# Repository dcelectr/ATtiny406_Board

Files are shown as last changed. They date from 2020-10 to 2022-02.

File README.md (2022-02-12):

# ATtiny406_Board
PCB Design Files for ATtiny406 Board

This board design is a variant of a board design that is found in the blog link below.

https://www.omzlo.com/articles/baremetal-programming-on-the-tinyavr-0-micro-controllers

The board features fairly easy to hand solder components, such as a SOIC20 IC and 0805 resistors, capacitors and LEDs, and it is breadboard friendly (100 mil spacing pin headers) with an orderly pin arrangement (PA0->PA7, PB0->PB5, and PC0->PC3). 

The programming connector is a standard FTDI USB-UART adapter pin-out. Since most FTDI USB-UART cables have different voltage for the Vcc and Vttl (such as the TTL-232R-3V3), a solder jumper (JP1) is open by default. The board can be powered from the breadboard pin headers or the FTDI programming header if the the jumper JP1 is closed. Using an FTDI TTL-232RG-VIP USB-UART requires the jumper JP1 to be closed so that the TTL-232RG-VIP adapter TTL voltage (Vttl) would be the same as the Vcc.

The Bill of Materials is also included (see file ATtiny406BOM.csv).

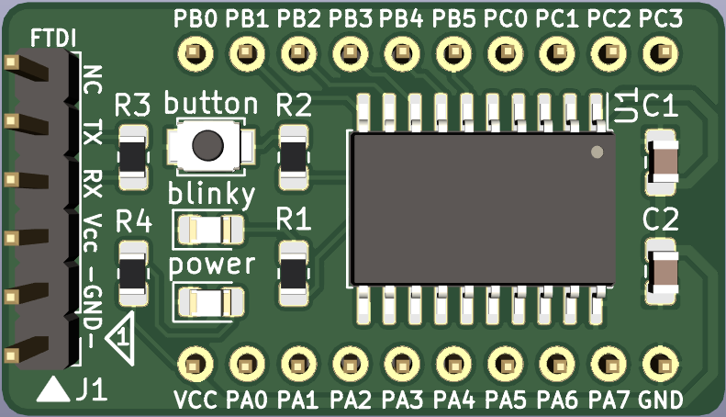
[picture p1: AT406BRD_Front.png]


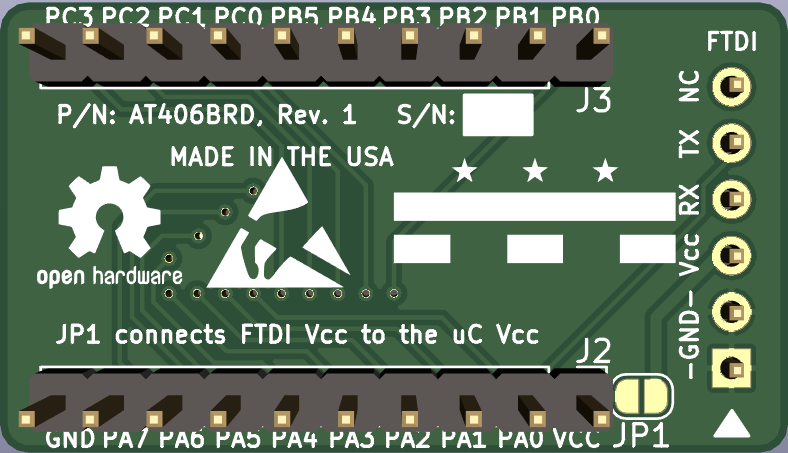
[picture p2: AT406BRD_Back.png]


Resistance of 4k7 Ohms works reliably for programming the Attiny406 over the range of Vcc, from 5V to 3V3.

Programming was tested on Linux with updiprog https://github.com/DCelectronics/updiprog (which is written in C) instead of using pyupdi.

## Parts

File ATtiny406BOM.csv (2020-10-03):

Reference | Quantity | Value | Footprint | Datasheet | P/N
C1 | 1 | 0.1uF | Capacitor_SMD:C_0805_2012Metric_Pad1.18x1.45mm_HandSolder | ~ | CC0805KRX7R7BB104
C2 | 1 | 2.2uF | Capacitor_SMD:C_0805_2012Metric_Pad1.18x1.45mm_HandSolder | ~ | CL21B225KOFNNNE
D1 | 1 | YEL | LED_SMD:LED_0805_2012Metric_Pad1.15x1.40mm_HandSolder | ~ | 150080YS75000
D2 | 1 | GRE | LED_SMD:LED_0805_2012Metric_Pad1.15x1.40mm_HandSolder | ~ | 150080VS75000
J1 | 1 | Conn_01x06_Male | Connector_PinHeader_2.54mm:PinHeader_1x06_P2.54mm_Vertical | ~ | PH1-06-UA
J2 J3 | 2 | Conn_01x10_Male | Connector_PinHeader_2.54mm:PinHeader_1x10_P2.54mm_Vertical | ~ | PH1-10-UA
JP1 | 1 | Jumper_2_Open | Jumper:SolderJumper-2_P1.3mm_Open_RoundedPad1.0x1.5mm | ~ | N/A
R1 R2 R4 | 3 | 1K | Resistor_SMD:R_0805_2012Metric_Pad1.20x1.40mm_HandSolder | ~ | ERJ-6GEYJ102V
R3 | 1 | 4K7 | Resistor_SMD:R_0805_2012Metric_Pad1.20x1.40mm_HandSolder | ~ | ERJ-6GEYJ472V
SW1 | 1 | SW_Push | Button_Switch_SMD:SW_SPST_B3U-1000P | ~ | B3U-1000P
U1 | 1 | ATtiny406-S | Package_SO:SOIC-20W_7.5x12.8mm_P1.27mm | http://ww1.microchip.com/downloads/en/DeviceDoc/Microchip%208bit%20mcu%20AVR%20ATtiny406%20data%20sheet%2040001976A.pdf | ATTINY406-SFR

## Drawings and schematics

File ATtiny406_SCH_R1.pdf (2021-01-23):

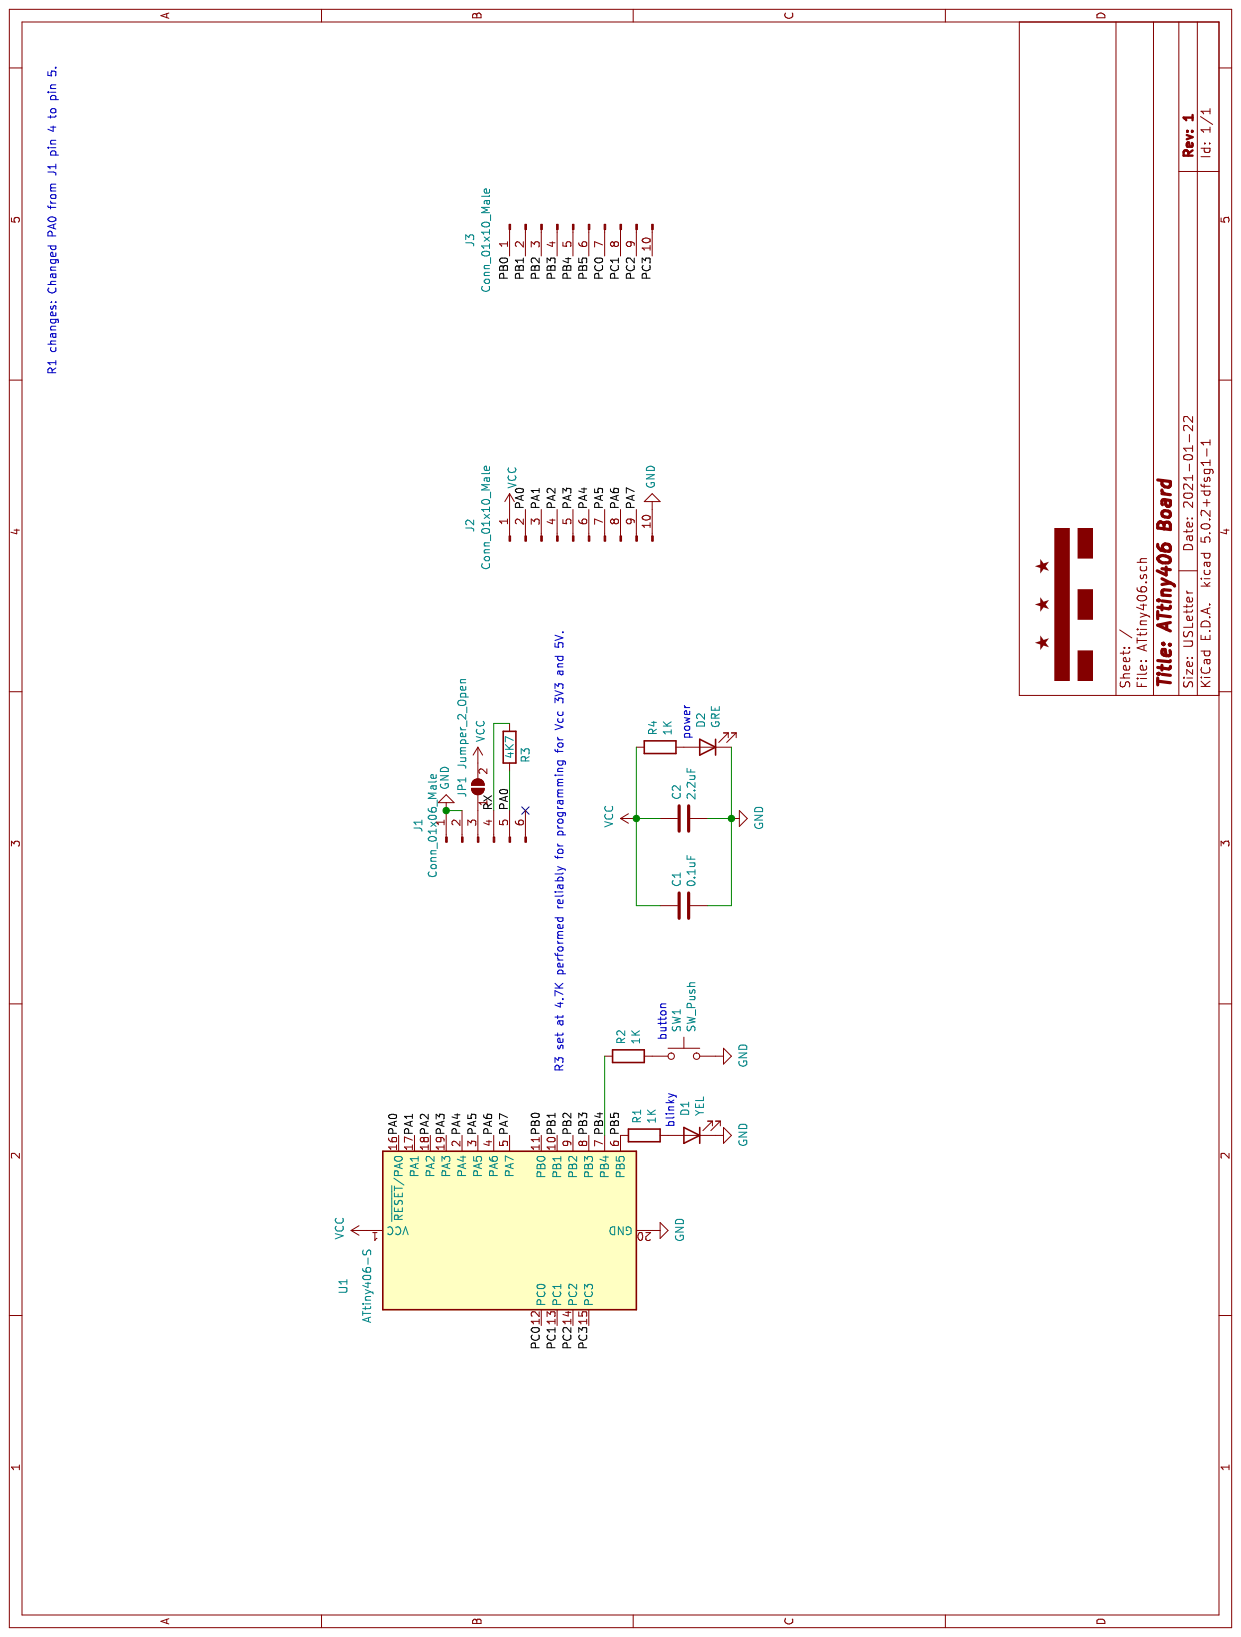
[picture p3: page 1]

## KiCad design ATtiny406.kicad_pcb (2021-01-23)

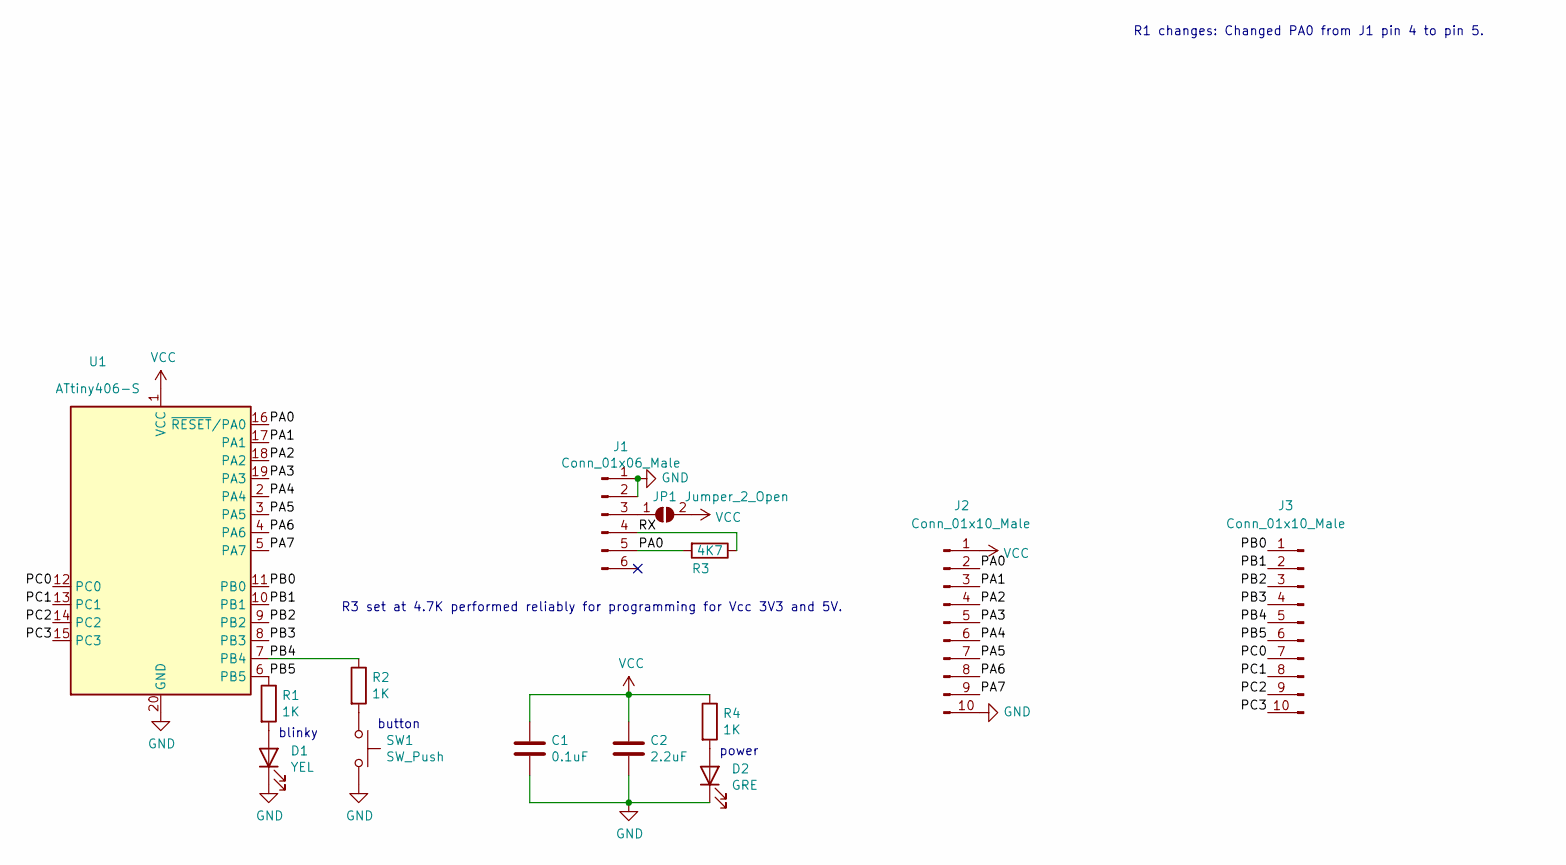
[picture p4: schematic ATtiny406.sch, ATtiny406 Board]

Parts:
C1: 0.1uF; C_0805_2012Metric_Pad1.18x1.45mm_HandSolder
C2: 2.2uF; C_0805_2012Metric_Pad1.18x1.45mm_HandSolder
D1: YEL; LED_0805_2012Metric_Pad1.15x1.40mm_HandSolder
D2: GRE; LED_0805_2012Metric_Pad1.15x1.40mm_HandSolder
J1: Conn_01x06_Male; PinHeader_1x06_P2.54mm_Vertical
J2, J3: Conn_01x10_Male; PinHeader_1x10_P2.54mm_Vertical
JP1: Jumper_2_Open; SolderJumper-2_P1.3mm_Open_RoundedPad1.0x1.5mm
R1, R2, R4: 1K; R_0805_2012Metric_Pad1.20x1.40mm_HandSolder
R3: 4K7; R_0805_2012Metric_Pad1.20x1.40mm_HandSolder
SW1: SW_Push; SW_SPST_B3U-1000P
U1: ATtiny406-S; SOIC-20W_7.5x12.8mm_P1.27mm

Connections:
/PA0: J1.5, J2.2, R3.2, U1.16 (~RESET~/PA0)
/PA1: J2.3, U1.17 (PA1)
/PA2: J2.4, U1.18 (PA2)
/PA3: J2.5, U1.19 (PA3)
/PA4: J2.6, U1.2 (PA4)
/PA5: J2.7, U1.3 (PA5)
/PA6: J2.8, U1.4 (PA6)
/PA7: J2.9, U1.5 (PA7)
/PB0: J3.1, U1.11 (PB0)
/PB1: J3.2, U1.10 (PB1)
/PB2: J3.3, U1.9 (PB2)
/PB3: J3.4, U1.8 (PB3)
/PB4: J3.5, R2.1, U1.7 (PB4)
/PB5: J3.6, R1.1, U1.6 (PB5)
/PC0: J3.7, U1.12 (PC0)
/PC1: J3.8, U1.13 (PC1)
/PC2: J3.9, U1.14 (PC2)
/PC3: J3.10, U1.15 (PC3)
/RX: J1.4, R3.1
GND: C1.2, C2.2, D1.1 (K), D2.1 (K), J1.1, J1.2, J2.10, SW1.2, U1.20 (GND)
unnamed: D1.2 (A), R1.2
unnamed: D2.2 (A), R4.2
unnamed: J1.3, JP1.1 (A)
unnamed: R2.2, SW1.1
VCC: C1.1, C2.1, J2.1, JP1.2 (B), R4.1, U1.1 (VCC)

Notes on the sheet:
power
blinky
button
R3 set at 4.7K performed reliably for programming for Vcc 3V3 and 5V.
R1 changes: Changed PA0 from J1 pin 4 to pin 5.

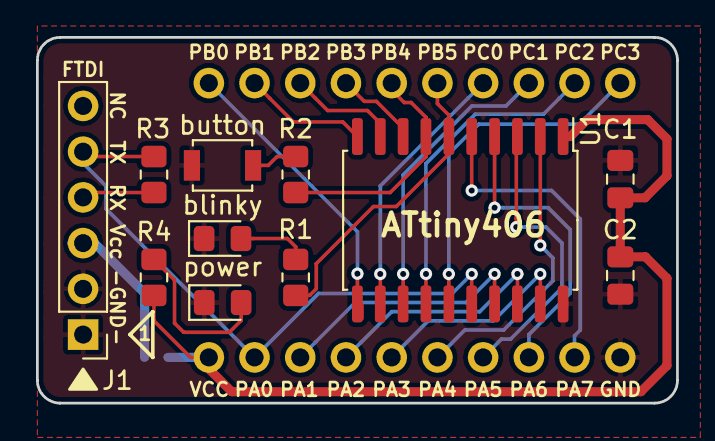
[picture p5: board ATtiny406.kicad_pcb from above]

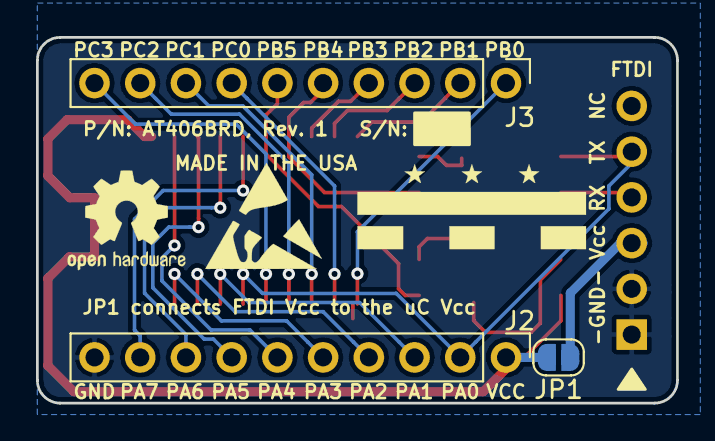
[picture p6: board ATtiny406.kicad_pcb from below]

Board: 2 copper layers, 35.6 x 20.3 mm, 14 parts (3 on the bottom side), 25 nets.
